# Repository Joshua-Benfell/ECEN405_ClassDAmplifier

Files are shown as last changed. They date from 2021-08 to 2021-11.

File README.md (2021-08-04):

# ECEN405_ClassDAmplifier

# Parts Checklist:
- [ ] [LPF 1](#lpf-1)
- [ ] [LPF 2](#lpf-2)
- [ ] [Gate Drivers](#gate-drivers) x 2
- [ ] Triangle wave generator block 
    - [ x ] [Comparator 1](#comparator-1) 
    - [ ] [Integrator](#integrator)
- [ ] [MOSFETs](#mosfets) x 2
- [ ] [Comparator 2](#comparator) 2
- [ ] [Inverter](#inverter)
- [ ] [Buffer](#buffer)

# System Overview
## Input Voltage
2V Peak to peak (+1V to -1V) with at least 1V input sensitivity. 

## Filters
### **Output Filter**
Needs to filter frequencies above 200Hz, but not the 200Hz point such that it has equivalent gain.  
Will likely need to be a Bridge Tied load (BTL) configuration, as BTL output filters do not require DC blocking caps, which limit the low frequency response of the amplifier, and can be quite large.  
  
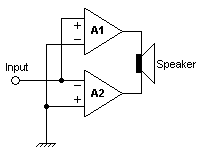
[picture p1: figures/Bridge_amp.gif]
  

Further reading: [on output filter types for class-d amplifiers](https://www.eetimes.com/understanding-output-filters-for-class-d-amplifiers/) and [BTL configurations on Wikipedia](https://en.wikipedia.org/wiki/Bridged_and_paralleled_amplifiers#Bridge-parallel_amplifier)  

### **Input Filter**
Cut-off point at 2kHz so that the cut-off is 1 decade above the 200Hz at the top of the bandwidth. This will avoid the phase change since it starts 1 decade before the cut-off. Make a Bode plot. No HPF for input as it is not needed. 
## Triangle Wave Generator
Possible approaches:
### **555 timer and an integrator**
To produce a clean triangle wave is complicated with a 555, simpler circuits with a 555 don't seem to guarantee a good output triangle wave. Furthermore, 55 timer circuits are more expensive and have a larger footprint.

### **Comparator integrator** 
A comparator integrator, is able to provide a reliably clean triangle wave and is fairly simple to implement.  
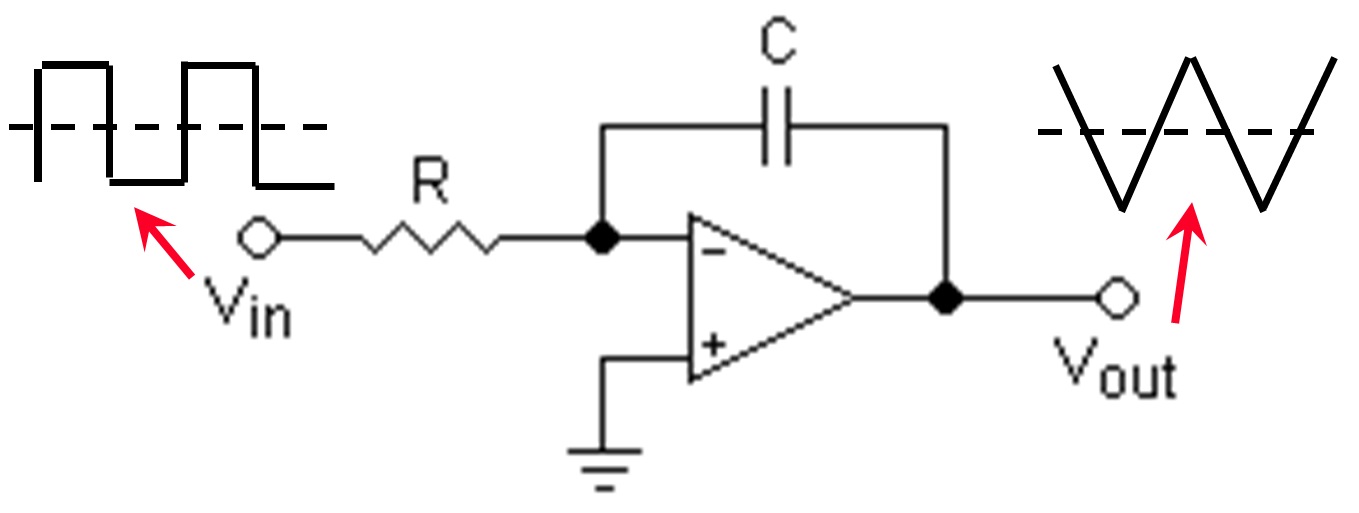
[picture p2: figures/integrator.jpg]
  
The frequency of the triangle wave will be above the audible range of frequencies at 22kHz.  
The package used will be: [MAX4016](https://www.digikey.co.nz/product-detail/en/maxim-integrated/MAX4016ESA/MAX4016ESA-ND/1702288)  
- 10V rail so that we don’t step down more again
- 5V middle because 50/50 v-divider is easy
- No dual rail because that is what a full bridge is for
- Also no whack shit - Danny B

## Switching Frequency
Two key constraints with switching frequency:  
1. As we are sampling an audio signal, it must be at least 10x the max frequency in our signal. The max signal frequency for the amplifier will be 200Hz, therefore the minimum sampling frequency must be 2kHz.
2. The switching frequency can't be audible, which means it must be outside of the audible range of frequencies to humans which is 20Hz - 20kHz. Adult humans typically can't hear more than 15 - 17kHz, making 20kHz a reasonable limit.
As a result the switching frequency must be **at least 20kHz**.

# Part Description and Justification
## LPF 1
## LPF 2
## Gate Drivers
### Requirements
- 18V Input
- 80W at 4 Ohms
- No integrated Fets
- Selectable Dead Time

### Selected
## Comparator 1
[MAX4016](https://www.digikey.co.nz/product-detail/en/maxim-integrated/MAX4016ESA/MAX4016ESA-ND/1702288)  
- 10V rail so that we don’t step down more again
- 5V middle because 50/50 v-divider is easy
- No dual rail because that is what a full bridge is for
- Also no whack shit - Danny B
## Integrator
## MOSFETs
## Comparator 2
## Inverter
## Buffer

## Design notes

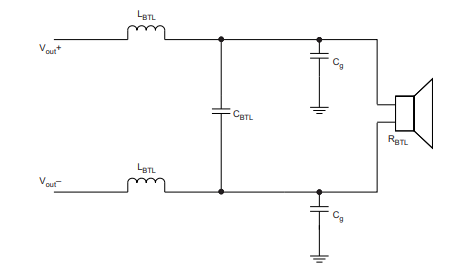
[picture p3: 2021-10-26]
figures/placeHolderOutputFilterSchematic.png

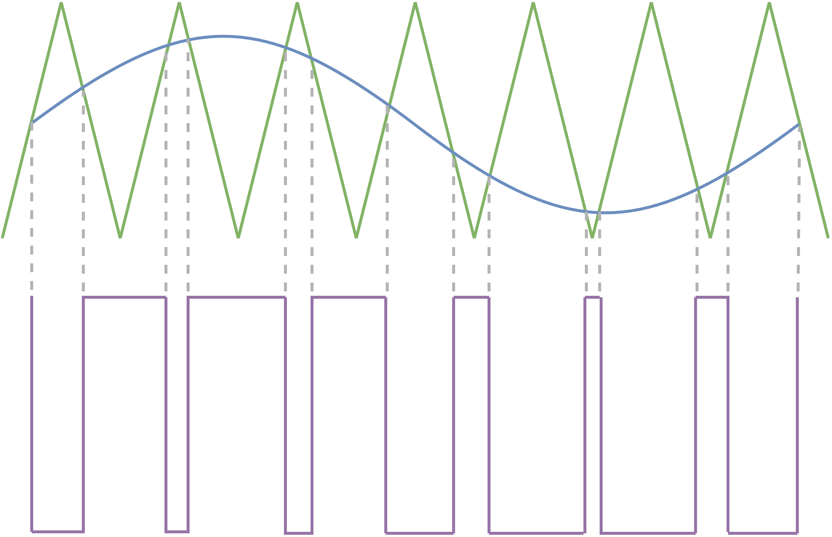
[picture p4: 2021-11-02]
figures/Waves_3.png

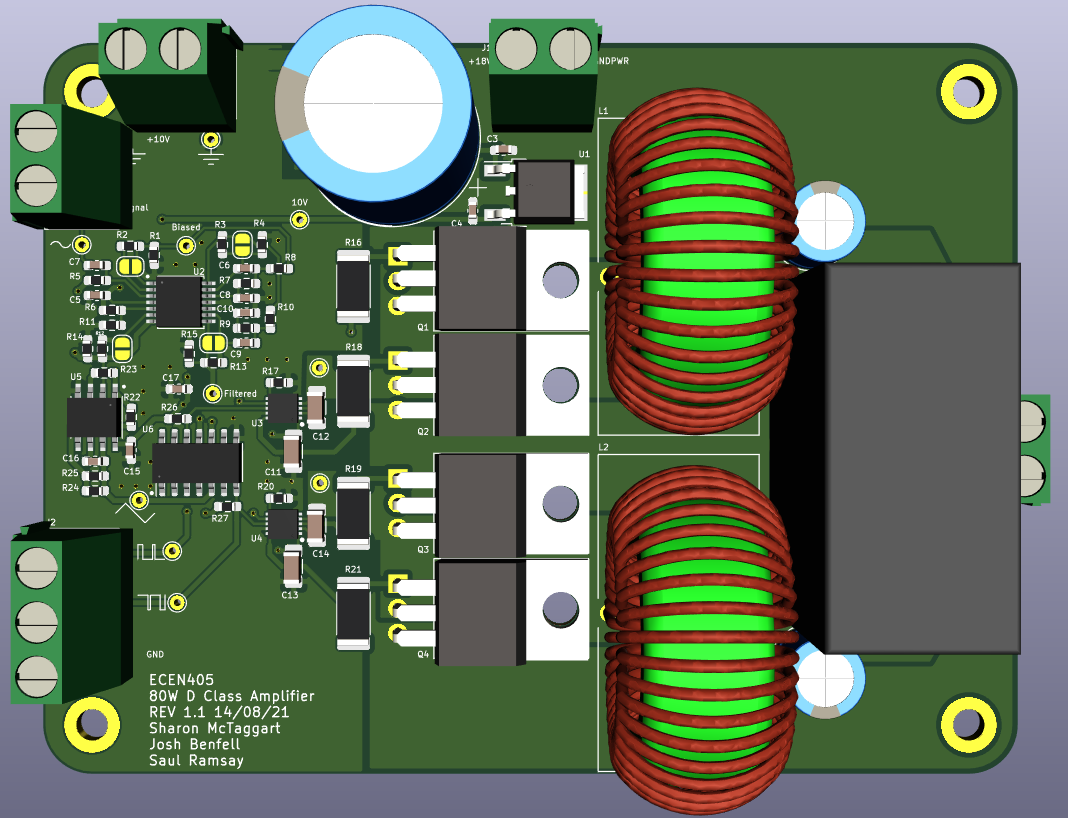
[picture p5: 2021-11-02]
figures/pcbRender.png

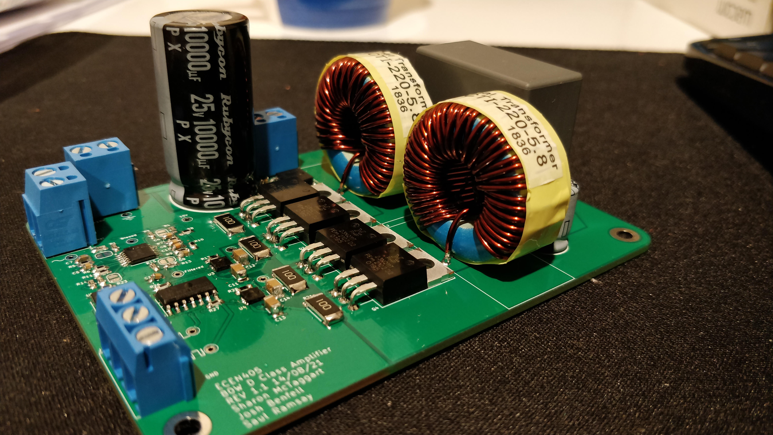
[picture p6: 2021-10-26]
figures/angleShot.jpg

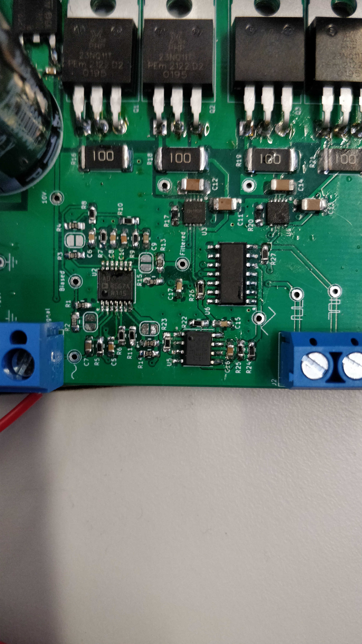
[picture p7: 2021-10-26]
figures/inputCloseup.jpg

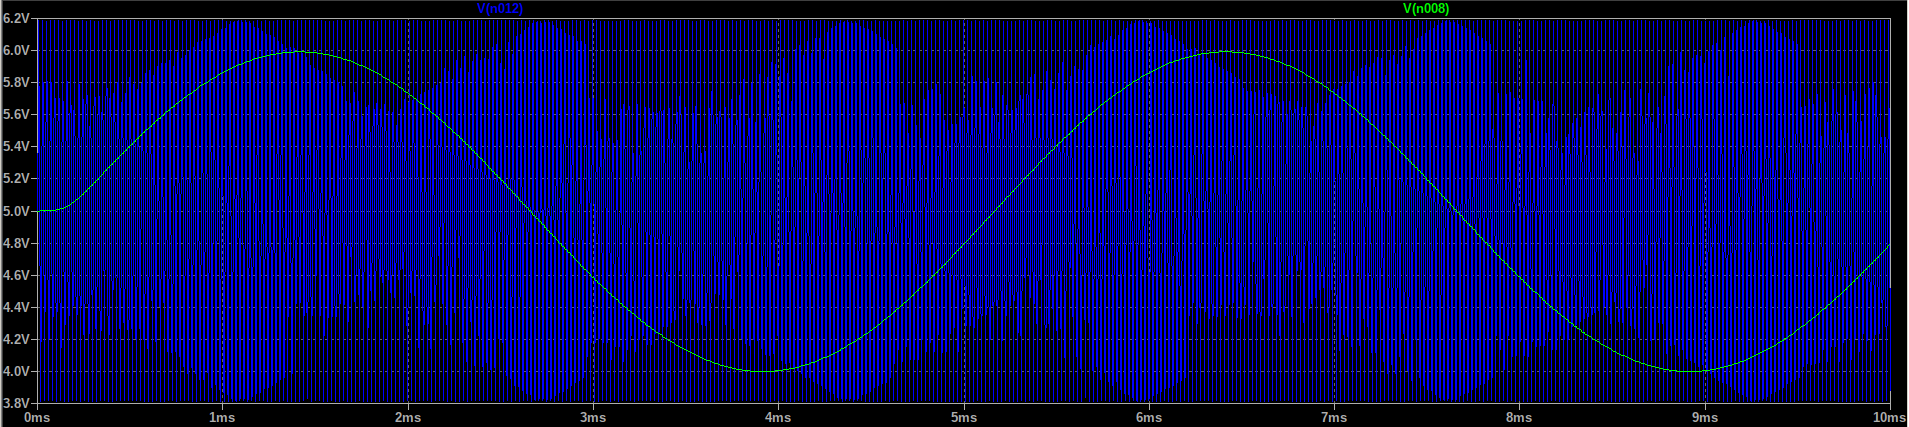
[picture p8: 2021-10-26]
figures/signalPlusTriangleWave.png

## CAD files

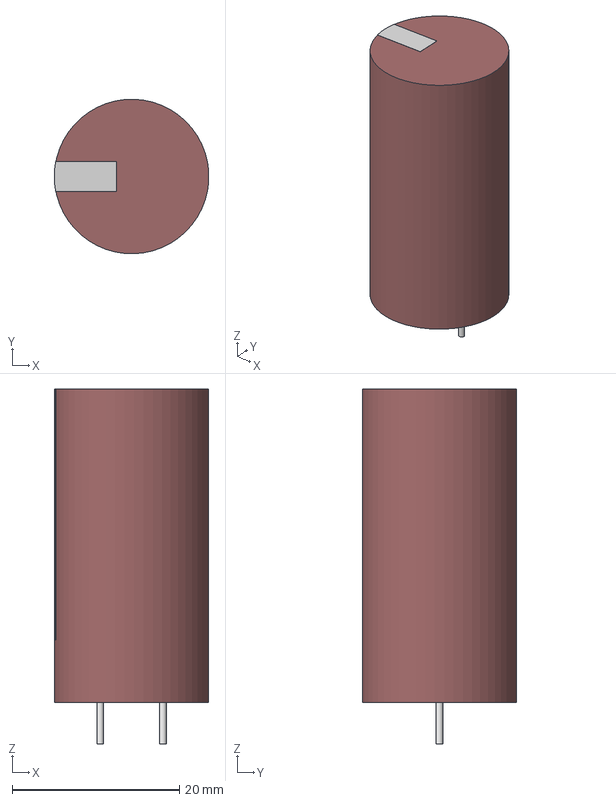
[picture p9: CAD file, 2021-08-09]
Kicad/3DModels/25PX10000MEFC18X35-5/CAP_PKPZ_18X35P5_RUB.step
18.5 x 18.5 x 42.5 mm

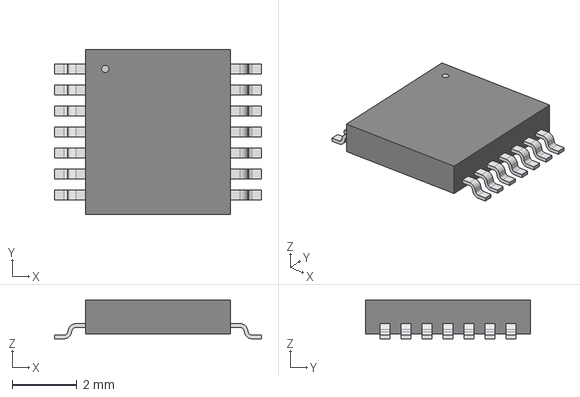
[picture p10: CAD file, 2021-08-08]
Kicad/3DModels/AD8567ARUZ/STEP/RU_14_ADI.step
6.40 x 5.11 x 1.20 mm

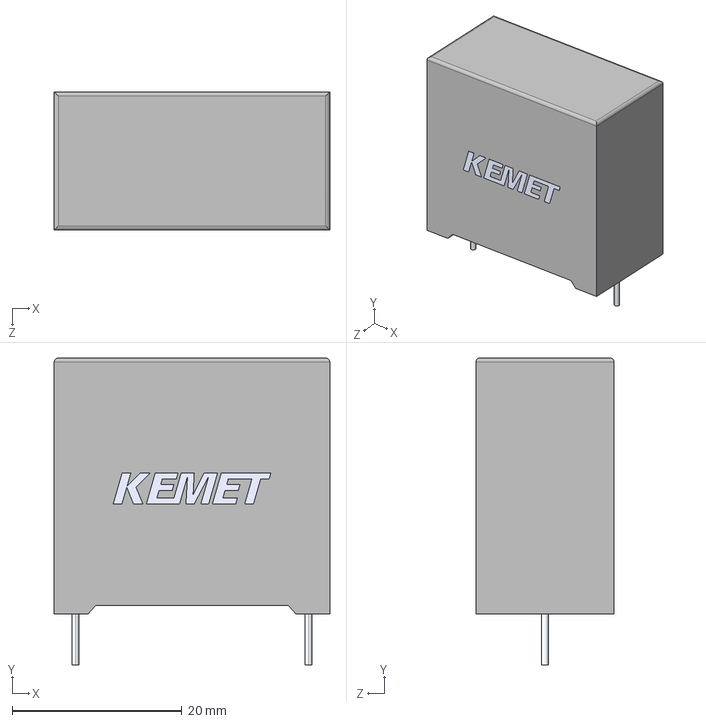
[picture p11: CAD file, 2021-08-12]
Kicad/3DModels/C4AQLBU5140M18K/C4AQLBU5140M18K.step
32.5 x 36.2 x 16.3 mm

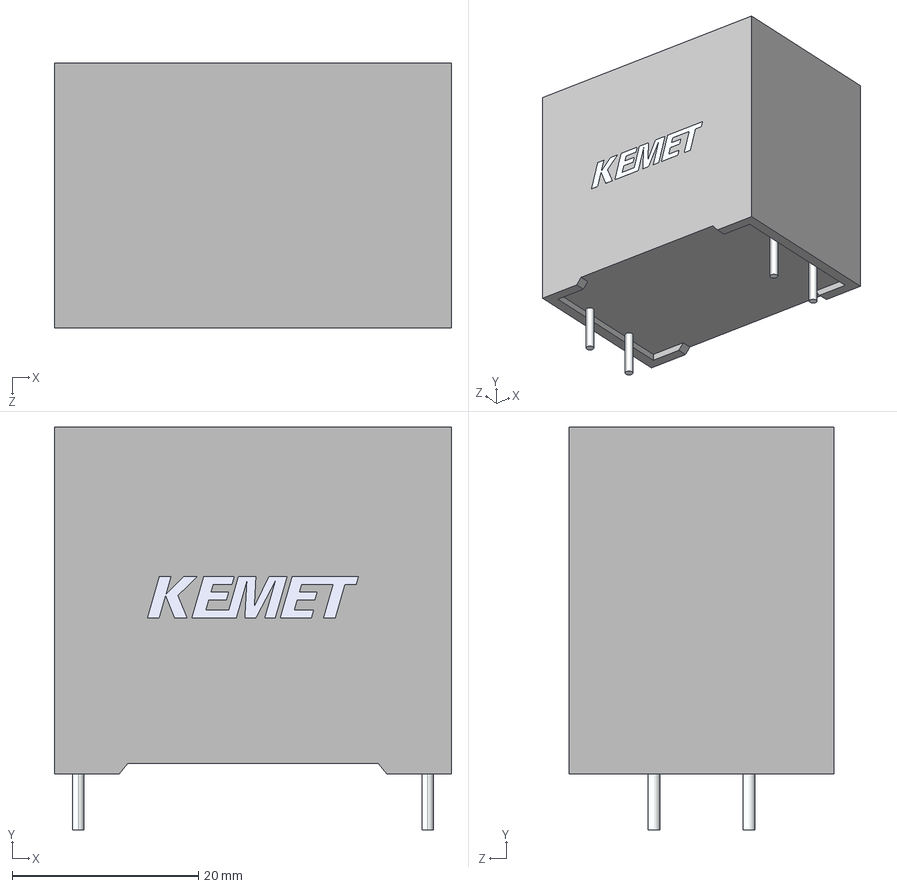
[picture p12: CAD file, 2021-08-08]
Kicad/3DModels/C4AQQBW5140A3JJ/C4AQQBW5140A3JJ.step
42.6 x 43.2 x 28.4 mm

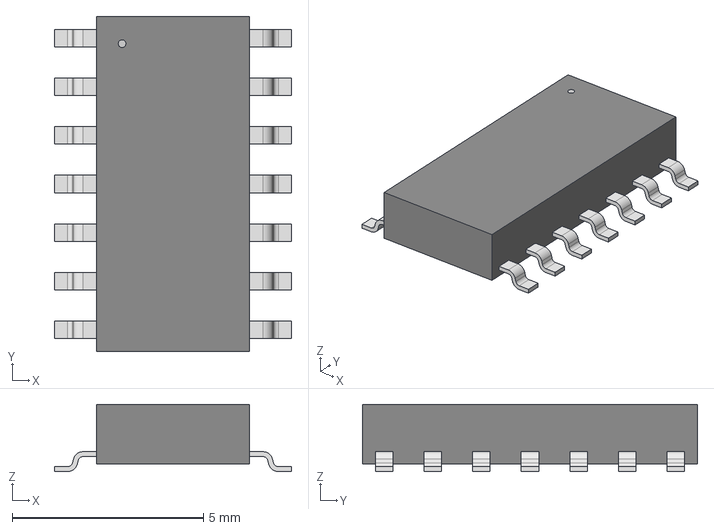
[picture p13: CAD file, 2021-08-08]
Kicad/3DModels/LM319DT/SO-14_STM.step
6.20 x 8.76 x 1.75 mm

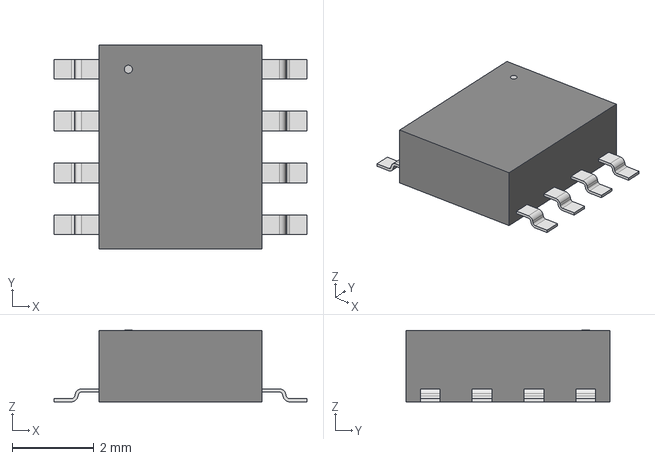
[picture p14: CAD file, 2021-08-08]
Kicad/3DModels/MAX4016ESA/STEP/21-0041B_8_MXM.step
6.20 x 5.00 x 1.75 mm

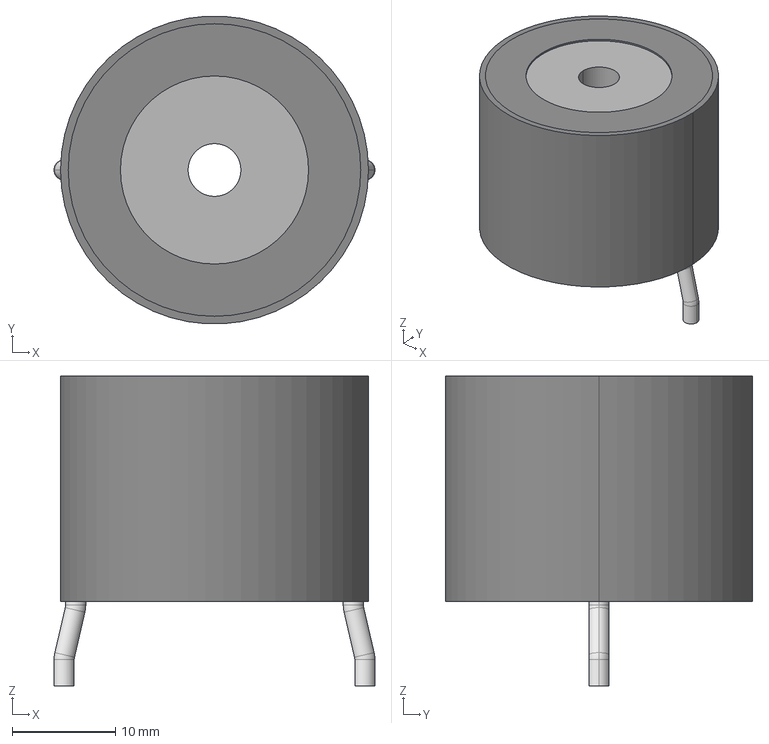
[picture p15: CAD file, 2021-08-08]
Kicad/3DModels/1422455C/1422455C_MUR.step
31.1 x 29.7 x 30.0 mm

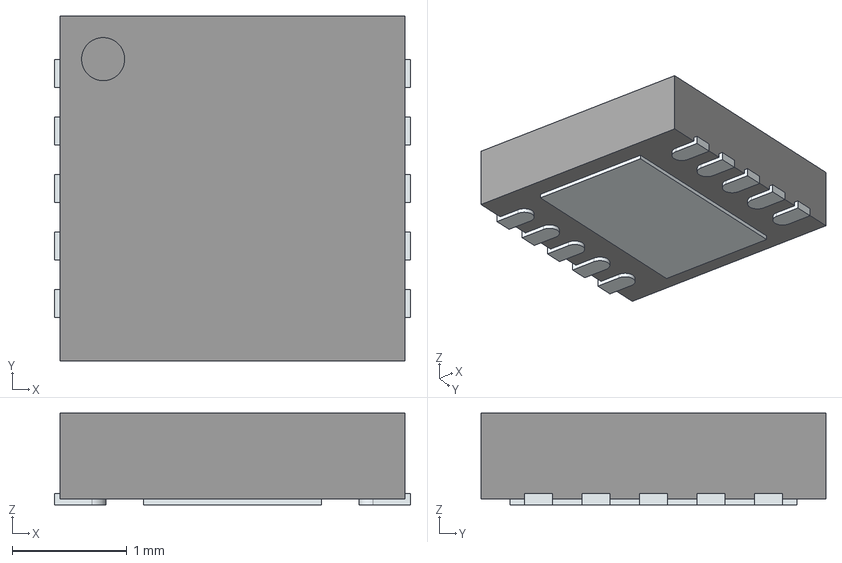
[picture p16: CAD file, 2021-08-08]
Kicad/3DModels/DGD05463FN-7/DGD05463FN-7.stp
3.10 x 3.00 x 0.8 mm
ThermalPin
PinsArrayLR

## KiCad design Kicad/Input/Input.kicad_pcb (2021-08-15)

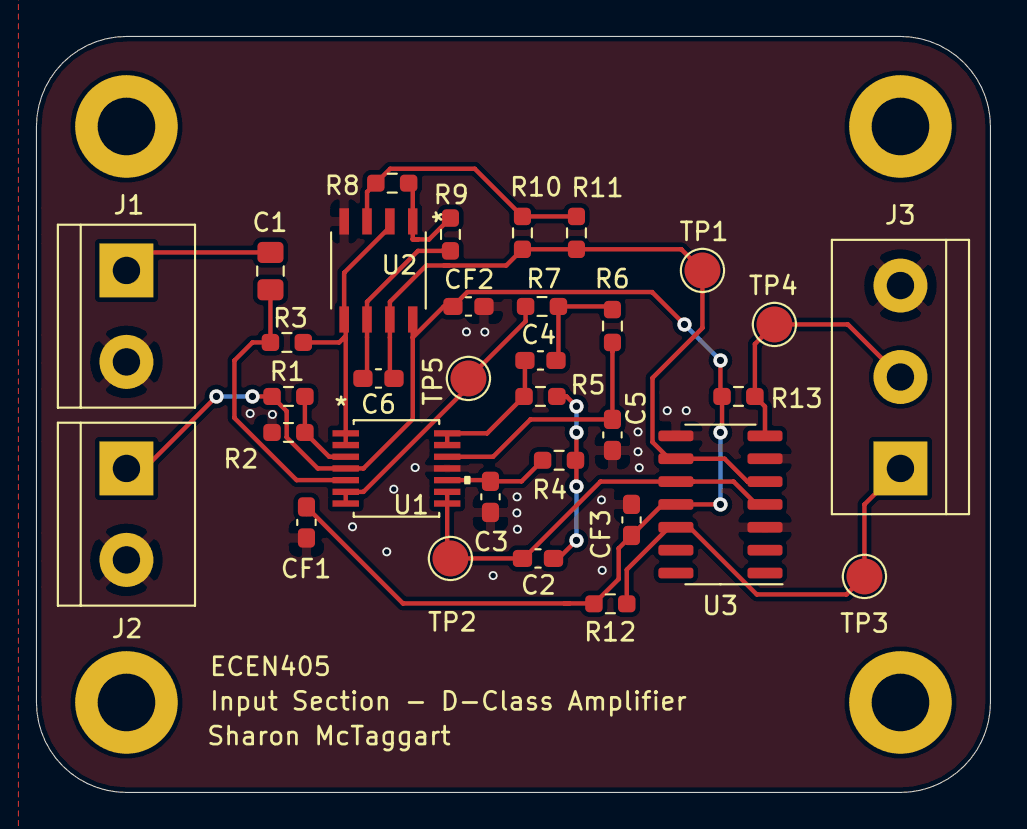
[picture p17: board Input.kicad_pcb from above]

Board: 2 copper layers, 53.0 x 42.0 mm, 37 parts (0 on the bottom side), 19 nets.

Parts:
C1: 10u; C_0805_2012Metric_Pad1.18x1.45mm_HandSolder
C2: 56n; C_0603_1608Metric_Pad1.08x0.95mm_HandSolder
C3: 5.6n; C_0603_1608Metric_Pad1.08x0.95mm_HandSolder
C4: 47n; C_0603_1608Metric_Pad1.08x0.95mm_HandSolder
C5: 4.7n; C_0603_1608Metric_Pad1.08x0.95mm_HandSolder
C6: 10n; C_0603_1608Metric_Pad1.08x0.95mm_HandSolder
CF1, CF2, CF3: 100n; C_0603_1608Metric_Pad1.08x0.95mm_HandSolder
H1, H2, H3, H4: MountingHole; MountingHole_3.2mm_M3_ISO7380_Pad
J1, J2: Conn_01x02; TerminalBlock_bornier-2_P5.08mm
J3: Conn_01x03; TerminalBlock_bornier-3_P5.08mm
R1, R2, R4, R12, R13: 10k; R_0603_1608Metric_Pad0.98x0.95mm_HandSolder
R3: 16k; R_0603_1608Metric_Pad0.98x0.95mm_HandSolder
R5: 750; R_0603_1608Metric_Pad0.98x0.95mm_HandSolder
R6: 22k; R_0603_1608Metric_Pad0.98x0.95mm_HandSolder
R7: 620; R_0603_1608Metric_Pad0.98x0.95mm_HandSolder
R8: 27k; R_0603_1608Metric_Pad0.98x0.95mm_HandSolder
R9: 2.2k; R_0603_1608Metric_Pad0.98x0.95mm_HandSolder
R10, R11: 12k; R_0603_1608Metric_Pad0.98x0.95mm_HandSolder
TP1, TP2, TP3, TP4, TP5: TestPoint; TestPoint_Pad_D2.0mm
U1: AD8567ARUZ
U2: MAX4016ESA+; MAX4016ESA&plus_
U3: LM319; SO-14_3.9x8.65mm_P1.27mm

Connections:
/Comparator/INV_PWM_OUT: J3.2, R13.2, TP4.1, U3.7
/Comparator/PWM_OUT: J3.1, R12.2, TP3.1, U3.12
/Comparator/SIG_IN: C2.2, TP2.1, U1.8, U1.9, U3.4, U3.10
/Comparator/TRIANGLE_IN: C6.1, R10.2, R11.2, TP1.1, U2.7, U3.5, U3.9
/LPF/BIASED_SIG: R7.1, TP5.1, U1.6, U1.7
/LPF/Filter_FirstStage: C4.1, R5.1, U1.13, U1.14
/LPF/SIG_IN: C1.2, J1.1
/LPF/VREF: R3.1, U1.1, U1.2, U2.2, U2.5
GND: C3.2, C5.2, CF1.2, CF2.2, CF3.2, J1.2, J2.2, J3.3, R2.2, U1.11, U2.4, U3.3, U3.6, U3.8
unnamed: C1.1, R3.2, U1.5
unnamed: C2.1, R4.1, R5.2
unnamed: C3.1, R4.2, U1.10
unnamed: C4.2, R6.1, R7.2
unnamed: C5.1, R6.2, U1.12
unnamed: C6.2, R9.1, U2.6
unnamed: R1.2, R2.1, U1.3
unnamed: R8.1, R9.2, U2.1
unnamed: R8.2, R10.1, R11.1, U2.3
VCC: CF1.1, CF2.1, CF3.1, J2.1, R1.1, R12.1, R13.1, U1.4, U2.8, U3.11

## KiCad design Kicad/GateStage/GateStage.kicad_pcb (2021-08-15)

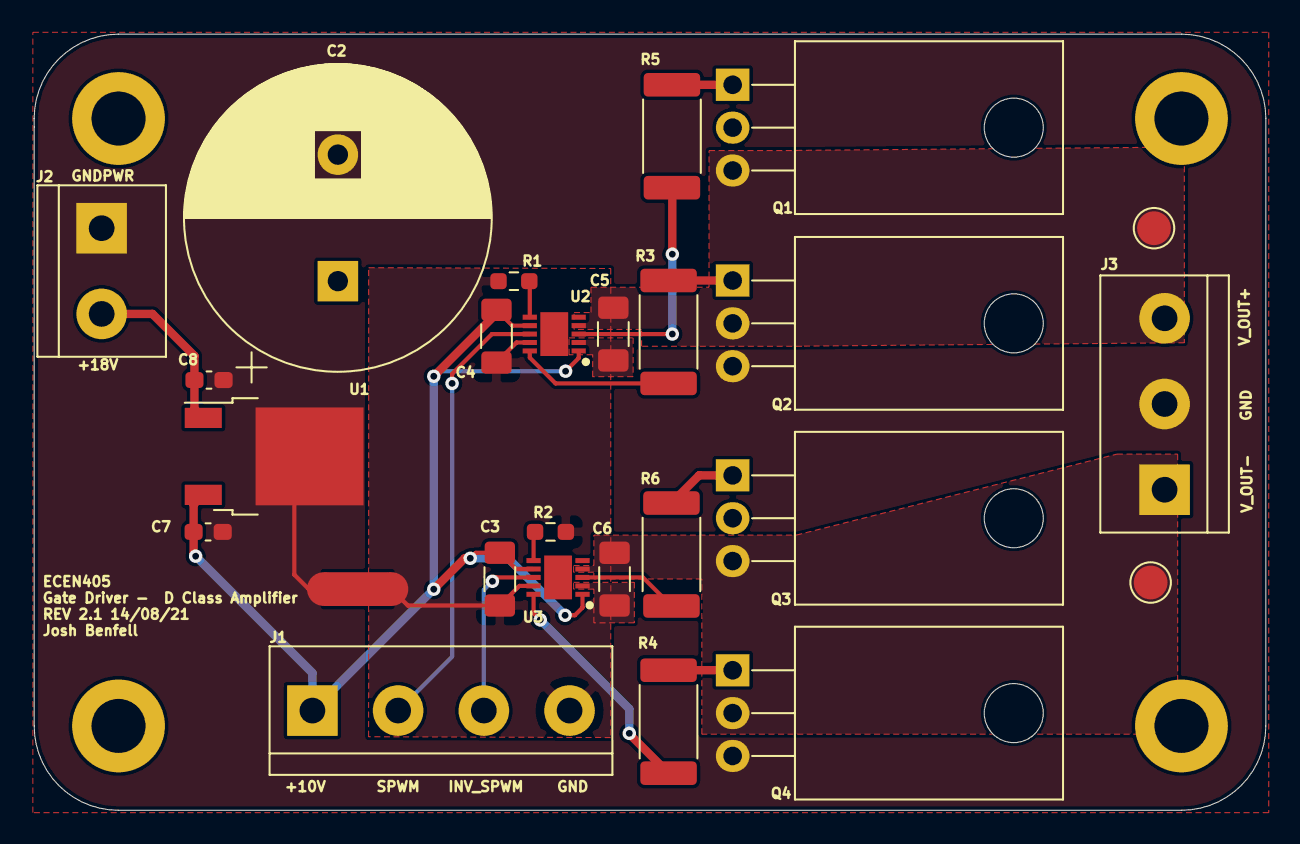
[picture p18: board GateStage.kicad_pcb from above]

Board: 2 copper layers, 73.0 x 46.0 mm, 31 parts (1 on the bottom side), 20 nets.

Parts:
C1, C3, C4, C5, C6: 10u 50V; C_1206_3216Metric_Pad1.33x1.80mm_HandSolder
C2: 10m; CP_Radial_D18.0mm_P7.50mm
C7: 100n; C_0603_1608Metric_Pad1.08x0.95mm_HandSolder
C8: 330n; C_0603_1608Metric_Pad1.08x0.95mm_HandSolder
H1, H2, H3, H4: MountingHole; MountingHole_3.2mm_M3_ISO14580_Pad
J1: Conn_01x04; TerminalBlock_bornier-4_P5.08mm
J2: Conn_01x02; TerminalBlock_bornier-2_P5.08mm
J3: Conn_01x03; TerminalBlock_bornier-3_P5.08mm
NT1: Net-Tie_2; NetTie-2_SMD_Pad2.0mm
Q1, Q2, Q3, Q4: PHP23NQ11T,127; TO-220-3_Horizontal_TabDown
R1, R2: 20k; R_0603_1608Metric_Pad0.98x0.95mm_HandSolder
R3, R4, R5, R6: 10; R_2512_6332Metric_Pad1.40x3.35mm_HandSolder
TP1, TP2: TestPoint; TestPoint_Pad_D2.0mm
U1: L78M10ABDT; TO-252-2
U2, U3: DGD05463FN-7; SON50P300X300X80-11N-D

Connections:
/H-Bridge/V_DT1: R1.1, U2.6
/H-Bridge/V_DT2: R2.1, U3.6
/H-Bridge/V_OUT+: C5.1, J3.3, Q1.3, Q2.2, TP1.1, U2.4
/H-Bridge/V_OUT-: C6.1, J3.1, Q3.3, Q4.2, TP2.1, U3.4
/INV_PWM: J1.3, U3.8
/PWM: J1.2, U2.8
GND: C3.1, C4.1, J1.4, NT1.1, R1.2, R2.2, U2.9, U3.9
GNDPWR: C1.2, C2.2, C7.2, C8.2, J2.1, J3.2, NT1.2, Q2.3, Q4.3, U1.2
unnamed: C5.2, U2.2
unnamed: C6.2, U3.2
unnamed: Q1.1, R5.1
unnamed: Q2.1, R3.1
unnamed: Q3.1, R6.1
unnamed: Q4.1, R4.1
unnamed: R3.2, U2.10
unnamed: R4.2, U3.10
unnamed: R5.2, U2.3
unnamed: R6.2, U3.3
VCC: C3.2, C4.2, C7.1, J1.1, U1.3, U2.1, U2.7, U3.1, U3.7
VDD: C1.1, C2.1, C8.1, J2.2, Q1.2, Q3.2, U1.1

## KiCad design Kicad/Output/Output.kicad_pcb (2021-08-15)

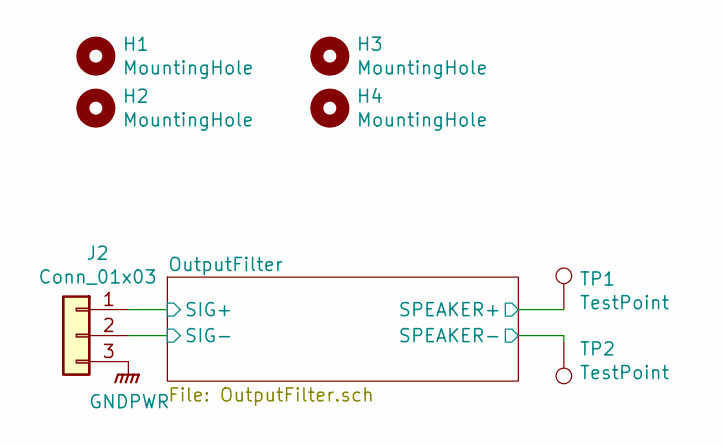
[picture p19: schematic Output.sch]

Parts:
H1, H2, H3, H4: MountingHole; MountingHole_3.2mm_M3_ISO7380_Pad
J2: Conn_01x03; TerminalBlock_bornier-3_P5.08mm
TP1, TP2: TestPoint; TestPoint_Pad_D2.0mm

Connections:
/OutputFilter/SIG+: J2.1; also elsewhere on the board
/OutputFilter/SIG-: J2.2; also elsewhere on the board
/OutputFilter/SPEAKER+: TP1.1; also elsewhere on the board
/OutputFilter/SPEAKER-: TP2.1; also elsewhere on the board
GNDPWR: J2.3; also elsewhere on the board

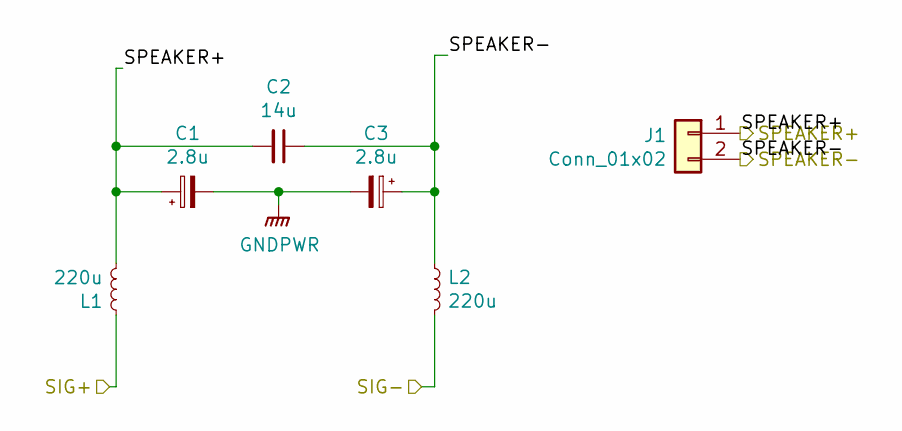
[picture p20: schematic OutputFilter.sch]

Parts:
C1, C3: 2.8u; CP_Radial_D8.0mm_P3.50mm
C2: 14u; C4AQLBU5140M18K
J1: Conn_01x02; TerminalBlock_bornier-2_P5.08mm
L1, L2: 220u; IND_HCTI-220-5.8

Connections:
/OutputFilter/SIG+: L1.1; also elsewhere on the board
/OutputFilter/SIG-: L2.2; also elsewhere on the board
/OutputFilter/SPEAKER+: C1.1, C2.2, J1.1, L1.2; also elsewhere on the board
/OutputFilter/SPEAKER-: C2.1, C3.1, J1.2, L2.1; also elsewhere on the board
GNDPWR: C1.2, C3.2; also elsewhere on the board

Board: 2 copper layers, 13 parts (0 on the bottom side), 5 nets, no tracks yet.

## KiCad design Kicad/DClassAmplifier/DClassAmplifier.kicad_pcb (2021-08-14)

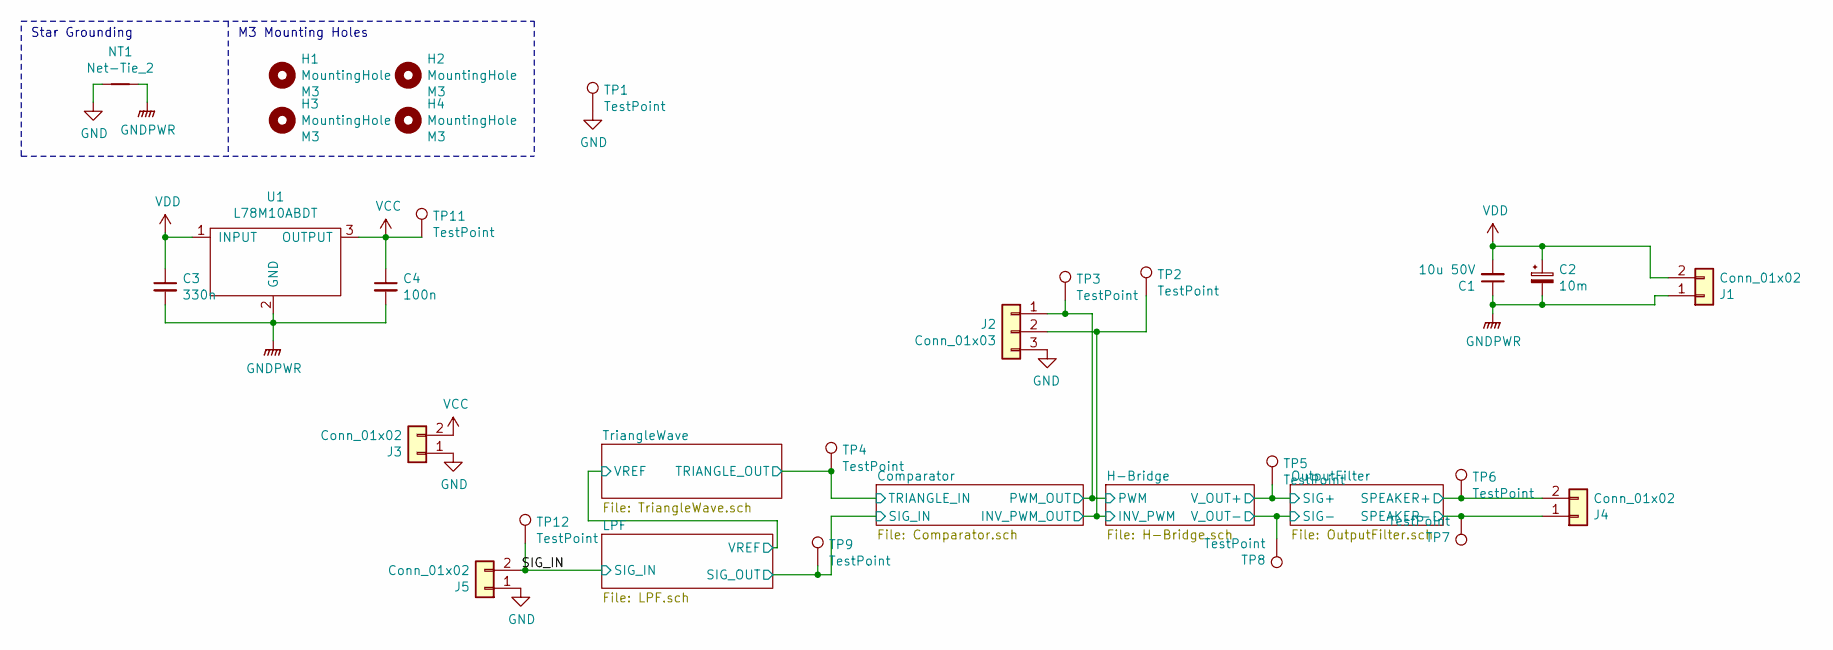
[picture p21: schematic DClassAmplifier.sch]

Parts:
C1: 10u 50V; C_1206_3216Metric_Pad1.33x1.80mm_HandSolder
C2: 10m; CP_Radial_D18.0mm_P7.50mm
C3: 330n; C_0603_1608Metric_Pad1.08x0.95mm_HandSolder
C4: 100n; C_0603_1608Metric_Pad1.08x0.95mm_HandSolder
H1, H2, H3, H4: MountingHole; MountingHole_3.2mm_M3_ISO7380_Pad
J1, J3, J4, J5: Conn_01x02; TerminalBlock_bornier-2_P5.08mm
J2: Conn_01x03; TerminalBlock_bornier-3_P5.08mm
NT1: Net-Tie_2; NetTie-2_SMD_Pad2.0mm
TP1, TP2, TP3, TP4, TP5, TP6, TP7, TP8, TP9, TP11, TP12: TestPoint; TestPoint_THTPad_D1.5mm_Drill0.7mm
U1: L78M10ABDT; TO-252-2

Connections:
/Comparator/SIG_IN: TP9.1; also elsewhere on the board
/Comparator/TRIANGLE_IN: TP4.1; also elsewhere on the board
/H-Bridge/INV_PWM: J2.2, TP2.1; also elsewhere on the board
/H-Bridge/PWM: J2.1, TP3.1; also elsewhere on the board
/OutputFilter/SIG+: TP5.1; also elsewhere on the board
/OutputFilter/SIG-: TP8.1; also elsewhere on the board
/OutputFilter/SPEAKER+: J4.2, TP6.1; also elsewhere on the board
/OutputFilter/SPEAKER-: J4.1, TP7.1; also elsewhere on the board
/SIG_IN: J5.2, TP12.1; also elsewhere on the board
GND: J2.3, J3.1, J5.1, NT1.1, TP1.1; also elsewhere on the board
GNDPWR: C1.1, C2.2, C3.2, C4.2, J1.1, NT1.2, U1.2 (GND); also elsewhere on the board
VCC: C4.1, J3.2, TP11.1, U1.3 (OUTPUT); also elsewhere on the board
VDD: C1.2, C2.1, C3.1, J1.2, U1.1 (INPUT); also elsewhere on the board

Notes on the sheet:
Star Grounding
M3 Mounting Holes

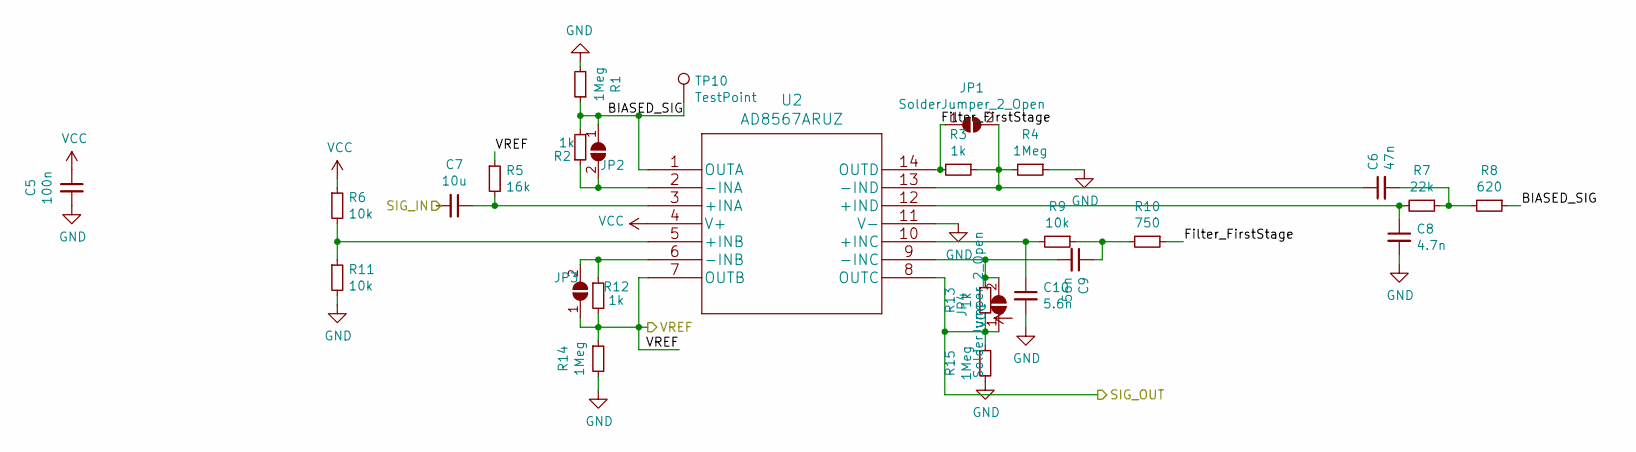
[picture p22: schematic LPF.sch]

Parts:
C5: 100n; C_0603_1608Metric_Pad1.08x0.95mm_HandSolder
C6: 47n; C_0603_1608Metric_Pad1.08x0.95mm_HandSolder
C7: 10u; C_0603_1608Metric_Pad1.08x0.95mm_HandSolder
C8: 4.7n; C_0603_1608Metric_Pad1.08x0.95mm_HandSolder
C9: 56n; C_0603_1608Metric_Pad1.08x0.95mm_HandSolder
C10: 5.6n; C_0603_1608Metric_Pad1.08x0.95mm_HandSolder
JP1, JP2, JP3, JP4: SolderJumper_2_Open; SolderJumper-2_P1.3mm_Open_RoundedPad1.0x1.5mm
R1, R4, R14, R15: 1Meg; R_0603_1608Metric_Pad0.98x0.95mm_HandSolder
R2, R3, R12, R13: 1k; R_0603_1608Metric_Pad0.98x0.95mm_HandSolder
R5: 16k; R_0603_1608Metric_Pad0.98x0.95mm_HandSolder
R6, R9, R11: 10k; R_0603_1608Metric_Pad0.98x0.95mm_HandSolder
R7: 22k; R_0603_1608Metric_Pad0.98x0.95mm_HandSolder
R8: 620; R_0603_1608Metric_Pad0.98x0.95mm_HandSolder
R10: 750; R_0603_1608Metric_Pad0.98x0.95mm_HandSolder
TP10: TestPoint; TestPoint_THTPad_D1.5mm_Drill0.7mm
U2: AD8567ARUZ

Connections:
/Comparator/SIG_IN: JP4.1 (A), R13.2, R15.1, U2.8 (OUTC); also elsewhere on the board
/LPF/BIASED_SIG: JP2.1 (A), R1.1, R2.2, R8.1, TP10.1, U2.1 (OUTA)
/LPF/Filter_FirstStage: JP1.1 (A), R3.2, R10.1, U2.14 (OUTD)
/LPF/VREF: JP3.1 (A), R5.1, R12.2, R14.1, U2.7 (OUTB); also elsewhere on the board
/SIG_IN: C7.2; also elsewhere on the board
GND: C5.2, C8.2, C10.2, R1.2, R4.1, R11.2, R14.2, R15.2, U2.11 (V-); also elsewhere on the board
unnamed: C6.1, JP1.2 (B), R3.1, R4.2, U2.13 (-IND)
unnamed: C6.2, R7.1, R8.2
unnamed: C7.1, R5.2, U2.3 (+INA)
unnamed: C8.1, R7.2, U2.12 (+IND)
unnamed: C9.1, R9.1, R10.2
unnamed: C9.2, JP4.2 (B), R13.1, U2.9 (-INC)
unnamed: C10.1, R9.2, U2.10 (+INC)
unnamed: JP2.2 (B), R2.1, U2.2 (-INA)
unnamed: JP3.2 (B), R12.1, U2.6 (-INB)
unnamed: R6.2, R11.1, U2.5 (+INB)
VCC: C5.1, R6.1, U2.4 (V+); also elsewhere on the board

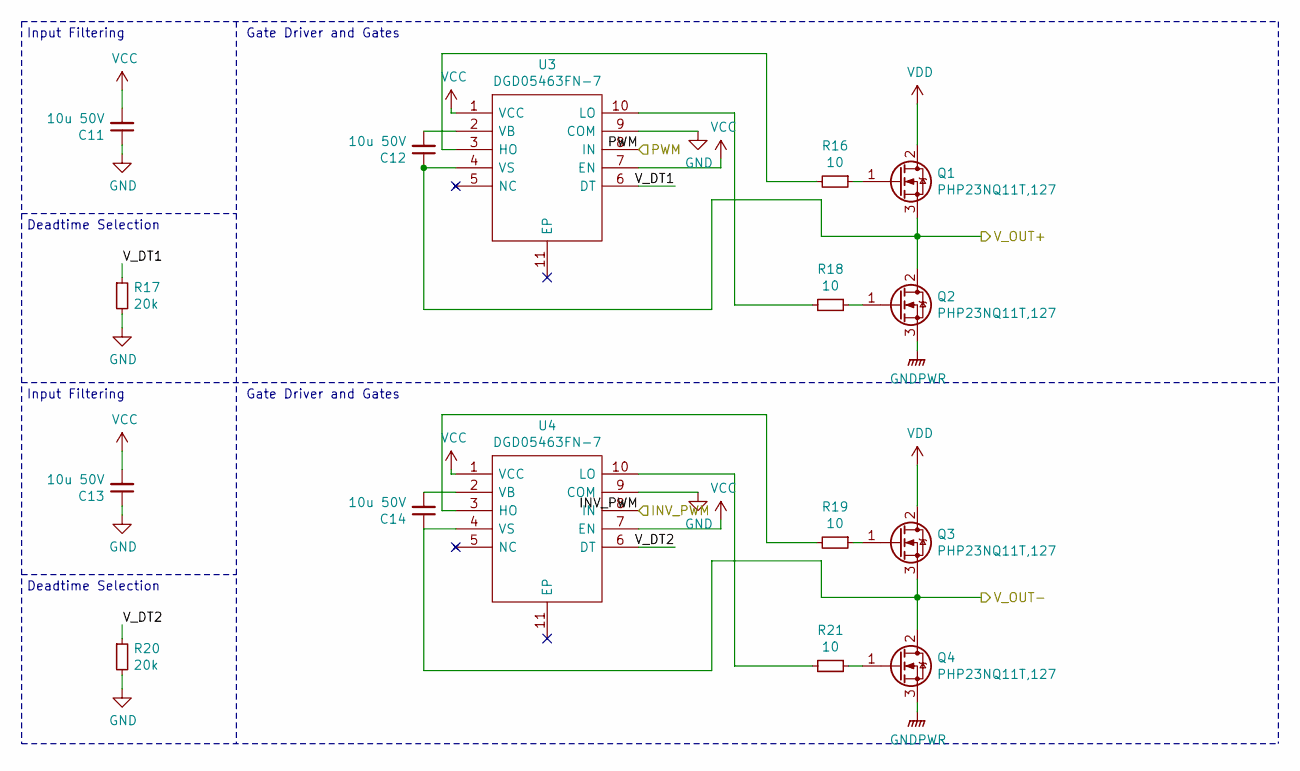
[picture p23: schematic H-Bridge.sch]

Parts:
C11, C12, C13, C14: 10u 50V; C_1206_3216Metric_Pad1.33x1.80mm_HandSolder
Q1, Q2, Q3, Q4: PHP23NQ11T,127; TO-220-3_Horizontal_TabDown
R16, R18, R19, R21: 10; R_2512_6332Metric_Pad1.40x3.35mm_HandSolder
R17, R20: 20k; R_0603_1608Metric_Pad0.98x0.95mm_HandSolder
U3, U4: DGD05463FN-7; SON50P300X300X80-11N-D; Manufacturer_Part_Number DGD05463FN-7; Mouser Part Number 621-DGD05463FN-7

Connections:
/H-Bridge/INV_PWM: U4.8 (IN); also elsewhere on the board
/H-Bridge/PWM: U3.8 (IN); also elsewhere on the board
/H-Bridge/V_DT1: R17.1, U3.6 (DT)
/H-Bridge/V_DT2: R20.1, U4.6 (DT)
/OutputFilter/SIG+: C12.1, Q1.3 (S), Q2.2 (D), U3.4 (VS); also elsewhere on the board
/OutputFilter/SIG-: C14.1, Q3.3 (S), Q4.2 (D), U4.4 (VS); also elsewhere on the board
GND: C11.1, C13.1, R17.2, R20.2, U3.9 (COM), U4.9 (COM); also elsewhere on the board
GNDPWR: Q2.3 (S), Q4.3 (S); also elsewhere on the board
unnamed: C12.2, U3.2 (VB)
unnamed: C14.2, U4.2 (VB)
unnamed: Q1.1 (G), R16.1
unnamed: Q2.1 (G), R18.1
unnamed: Q3.1 (G), R19.1
unnamed: Q4.1 (G), R21.1
unnamed: R16.2, U3.3 (HO)
unnamed: R18.2, U3.10 (LO)
unnamed: R19.2, U4.3 (HO)
unnamed: R21.2, U4.10 (LO)
VCC: C11.2, C13.2, U3.1 (VCC), U3.7 (EN), U4.1 (VCC), U4.7 (EN); also elsewhere on the board
VDD: Q1.2 (D), Q3.2 (D); also elsewhere on the board

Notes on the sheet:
Input Filtering
Deadtime Selection
Gate Driver and Gates

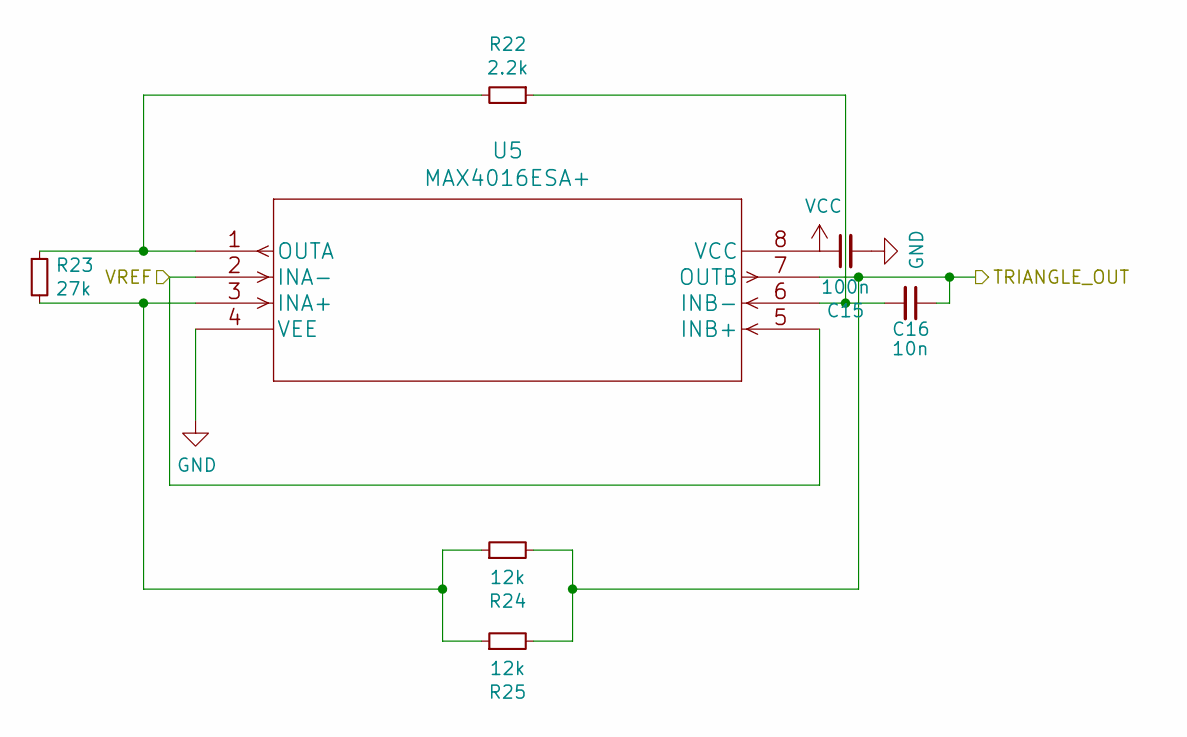
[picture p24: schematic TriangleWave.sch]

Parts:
C15: 100n; C_0603_1608Metric_Pad1.08x0.95mm_HandSolder
C16: 10n; C_0603_1608Metric_Pad1.08x0.95mm_HandSolder
R22: 2.2k; R_0603_1608Metric_Pad0.98x0.95mm_HandSolder
R23: 27k; R_0603_1608Metric_Pad0.98x0.95mm_HandSolder
R24, R25: 12k; R_0603_1608Metric_Pad0.98x0.95mm_HandSolder
U5: MAX4016ESA+; MAX4016ESA&plus_

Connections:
/Comparator/TRIANGLE_IN: C16.1, R24.2, R25.2, U5.7 (OUTB); also elsewhere on the board
/LPF/VREF: U5.2 (INA-), U5.5 (INB+); also elsewhere on the board
GND: C15.2, U5.4 (VEE); also elsewhere on the board
unnamed: C16.2, R22.1, U5.6 (INB-)
unnamed: R22.2, R23.1, U5.1 (OUTA)
unnamed: R23.2, R24.1, R25.1, U5.3 (INA+)
VCC: C15.1, U5.8 (VCC); also elsewhere on the board

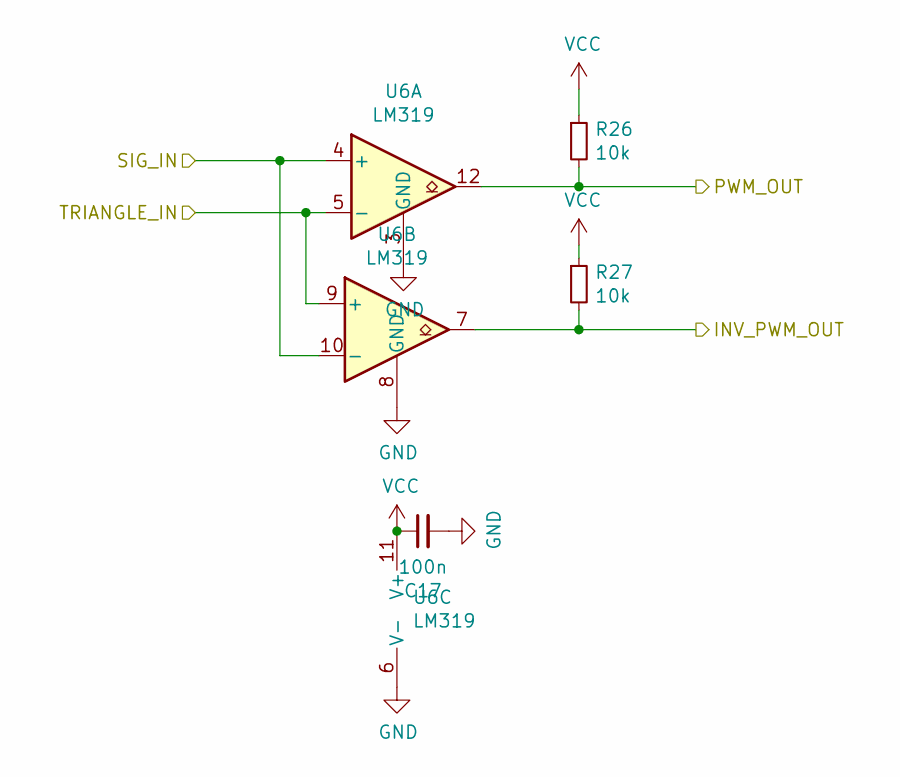
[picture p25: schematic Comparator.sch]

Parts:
C17: 100n; C_0603_1608Metric_Pad1.08x0.95mm_HandSolder
R26, R27: 10k; R_0603_1608Metric_Pad0.98x0.95mm_HandSolder
U6: LM319; SO-14_3.9x8.65mm_P1.27mm

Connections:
/Comparator/SIG_IN: U6.4 (+), U6.10 (-); also elsewhere on the board
/Comparator/TRIANGLE_IN: U6.5 (-), U6.9 (+); also elsewhere on the board
/H-Bridge/INV_PWM: R27.2, U6.7; also elsewhere on the board
/H-Bridge/PWM: R26.2, U6.12; also elsewhere on the board
GND: C17.2, U6.3 (GND), U6.6 (V-), U6.8 (GND); also elsewhere on the board
VCC: C17.1, R26.1, R27.1, U6.11 (V+); also elsewhere on the board

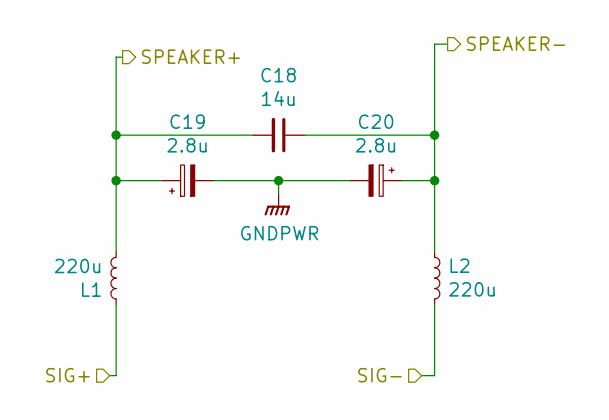
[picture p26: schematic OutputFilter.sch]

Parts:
C18: 14u; C4AQLBU5140M18K
C19, C20: 2.8u; CP_Radial_D8.0mm_P3.50mm
L1, L2: 220u; IND_HCTI-220-5.8

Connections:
/OutputFilter/SIG+: L1.1; also elsewhere on the board
/OutputFilter/SIG-: L2.2; also elsewhere on the board
/OutputFilter/SPEAKER+: C18.2, C19.1, L1.2; also elsewhere on the board
/OutputFilter/SPEAKER-: C18.1, C20.1, L2.1; also elsewhere on the board
GNDPWR: C19.2, C20.2; also elsewhere on the board

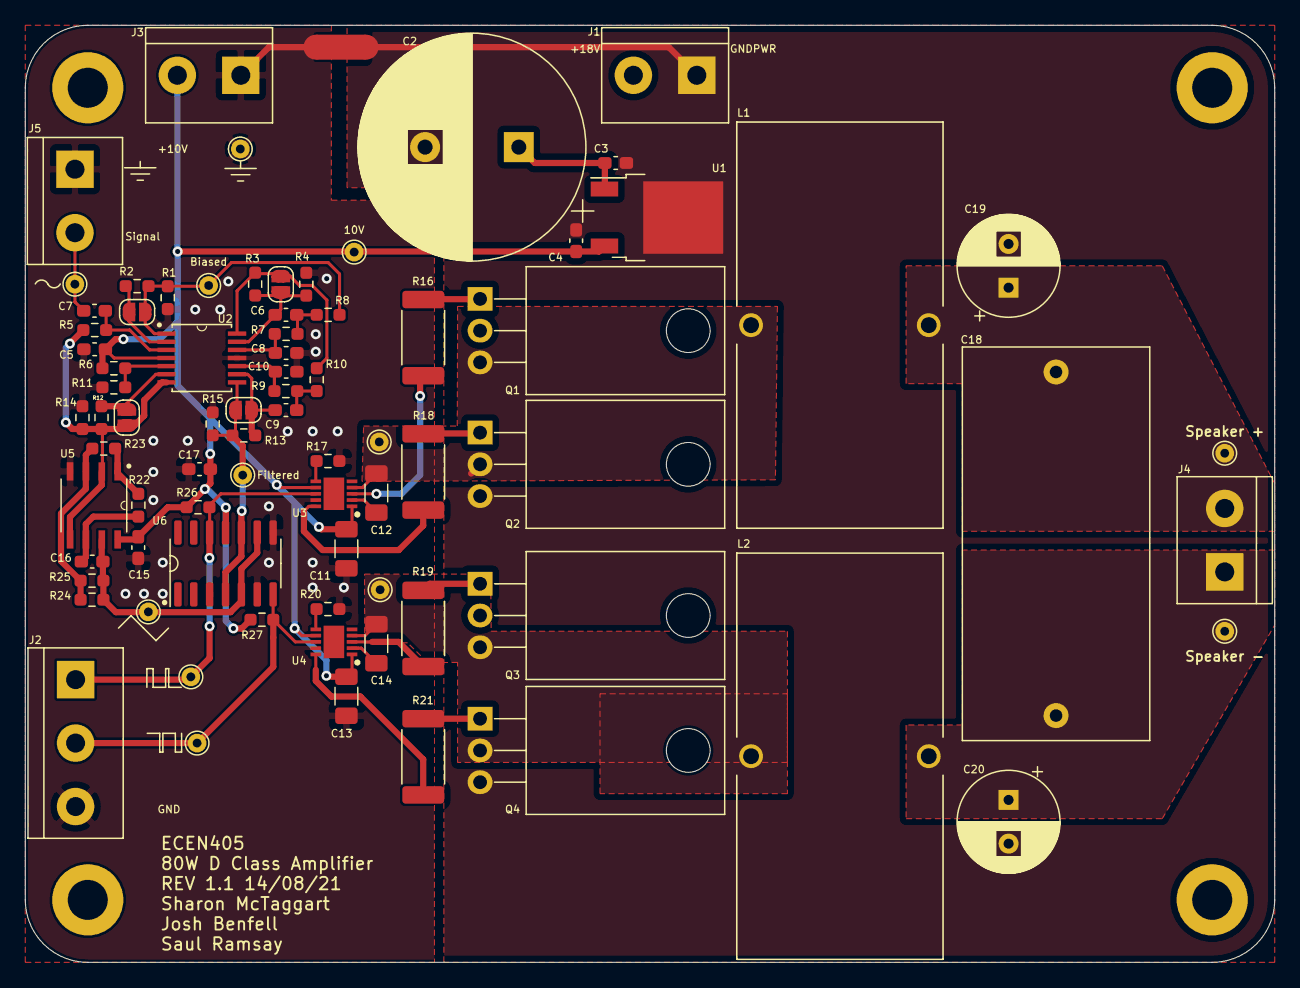
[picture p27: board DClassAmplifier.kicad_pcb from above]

Board: 2 copper layers, 100.0 x 75.0 mm, 85 parts (1 on the bottom side), 41 nets.

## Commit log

2021-07-21 Initial Kicad File Commit
    [DClassAmplifier.kicad_pcb, DClassAmplifier.sch, OutputFilter.sch]
2021-07-25 Added Net-Tied Grounds and Filter schematic
    [DClassAmplifier.sch, OutputFilter.sch]
2021-07-25 Create Additional Needed Hierarchical Schematics. Add Mounting Holes
    [DClassAmplifier.sch, Feedback.sch, H-Bridge.sch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]
2021-07-25 Add Gate Driver Library and To Schematic
    [DClassAmplifier.sch, Feedback.sch, H-Bridge.sch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]
2021-07-27 FET Selection
    [DClassAmplifier.sch, H-Bridge.sch]
2021-07-29 Sizing Gate Driver Components
    [DClassAmplifier.sch, H-Bridge.sch]
2021-07-30 Start Output Filter Spice File
2021-07-30 Work on getting filters working
2021-07-30 Added Dummy Comparator to schematic and duplicated drive.
    [DClassAmplifier.sch, Feedback.sch, H-Bridge.sch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]
2021-08-03 Hierarchical Comparator Sheet
    Updated Gate Driver as well
    [Comparator.sch, DClassAmplifier.sch, Feedback.sch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]
2021-08-03 Input stage
2021-08-03 Add files via upload
    Summing circuit with dual 10V rails to add a 5V bias
2021-08-03 10V input triangle wave
2021-08-03 Combine Triangle wave and Input Biasing/Filtering
2021-08-03 Lol Whoops, changes??
    Oh it was me moving things around a little bit
    [DClassAmplifier.sch]
2021-08-04 Design Updates for LTSpice and KiCad
    [Comparator.sch, DClassAmplifier.sch, Feedback.sch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]
2021-08-07 Values fixed
    40kHz triangle wave. Active LPF with 2kHz cut-off frequency.
2021-08-07 Update Output Filter
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2021-08-08 Output & Input Filter Final Designs
2021-08-08 Finish off Main Part of Schematic
    [Comparator.sch, DClassAmplifier.sch, Feedback.sch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]
2021-08-08 updates to schematic
    [Comparator.sch, DClassAmplifier.sch, H-Bridge.sch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]
2021-08-08 Add Filter Op Amp
    [21-0041B_8_MXM.step, RU_14_ADI.step]
2021-08-08 Update Opamp for Input Filter
    [Comparator.sch, DClassAmplifier.sch, H-Bridge.sch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]
2021-08-08 Added footprints to schematic
    [Comparator.sch, DClassAmplifier.sch, H-Bridge.sch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]
2021-08-08 Update Terminal Block Footprints
    [Comparator.sch, H-Bridge.sch, LPF.sch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]
2021-08-08 Add Test Points
    [Comparator.sch, DClassAmplifier.sch, H-Bridge.sch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]
2021-08-08 Load Components into PCBDOC
    [DClassAmplifier.kicad_pcb, LPF.sch, TriangleWave.sch]
2021-08-08 Add 3D Models
    [1422455C_MUR.step, C4AQQBW5140A3JJ.step, DClassAmplifier.kicad_pcb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]
2021-08-09 Add 10m Resevoir Cap
    [CAP_PKPZ_18X35P5_RUB.step, DClassAmplifier.kicad_pcb, DClassAmplifier.sch]
2021-08-10 Added input to global schematic
    Changed the sig_in net label in the LPF sheet to a hierarchical net label of the same name
    [DClassAmplifier.sch, H-Bridge.sch, LPF.sch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]
2021-08-10 Create Separate Projects for Each Board Layout
    [Comparator.sch, GateStage.kicad_pcb, GateStage.sch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]
2021-08-11 Prepared O/P Filter PCB for track layout
    Laid out components for Output Filter PCB compactly ready for tracks to be drawn. Have drawn out precise margin lines too.
    [Output.kicad_pcb, Output.sch, OutputFilter.sch]
2021-08-11 Gate Drive Board V 1
    [GateStage.kicad_pcb, GateStage.sch, H-Bridge.sch]
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2021-08-11 Saving changes before updating library
    [Output.kicad_pcb]
2021-08-11 OP Filter PCB Done
    OP Filter PCB finished
    [Output.kicad_pcb, OutputFilter.sch]
2021-08-11 Input PCB added
    [Comparator.sch, Input.kicad_pcb, Input.sch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]
2021-08-12 SilkS on Gate Driver Board
    [GateStage.kicad_pcb]
2021-08-12 Flipped J2, added connector labels
    Flipped J2 and re-drew planes to connect Sig + and - respectively .
    Also added labels for all the connections for J1 and J2 as well as the testpoints
    [Output.kicad_pcb]
2021-08-12 PCB for input and added filter caps
    [Comparator.sch, Input.kicad_pcb, LPF.sch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]
2021-08-12 Switched around component sides to match connector
    [Output.kicad_pcb]
2021-08-12 Moved filter caps (slightly)
    Shifted them such that they're as close as possible to the larger cap with enough physical clearance, and made the both symmetrical too
    [Output.kicad_pcb]
2021-08-12 Add SilkScreen to Film Cap Footprint
    [Output.kicad_pcb]
2021-08-12 Add Alternative Cap Footprint
2021-08-12 Add Alternative Cap 3D Model
    [C4AQLBU5140M18K.step]
2021-08-12 Combined Board
    [Comparator.sch, DClassAmplifier.kicad_pcb, DClassAmplifier.sch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]
2021-08-14 Add 10V Reg and Reroute
    [Comparator.sch, DClassAmplifier.kicad_pcb, DClassAmplifier.sch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]
2021-08-14 Graphics and SilkScreen Improvement
    [DClassAmplifier.kicad_pcb, DClassAmplifier.sch]
2021-08-14 Generate Fabrication Outputs
    [DClassAmplifier-B_Cu.gbl, DClassAmplifier-B_Mask.gbs, DClassAmplifier-B_Paste.gbp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]
2021-08-14 Whoops final Save
    [DClassAmplifier.kicad_pcb]
2021-08-14 Redo GateStage Board
    [GateStage.kicad_pcb, GateStage.sch, H-Bridge.sch]
2021-08-14 Move Combined Board Fabrication Outputs
    [DClassAmplifier-B_Cu.gbl, DClassAmplifier-B_Mask.gbs, DClassAmplifier-B_Paste.gbp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]
2021-08-14 Create GateStage Fabrication Outputs
    [GateStage-B_Cu.gbl, GateStage-B_Mask.gbs, GateStage-B_Paste.gbp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]
2021-08-15 Make Output Filter Board Smaller
    [Output.kicad_pcb, OutputFilter.sch]
2021-08-15 Label GateStage Board, Redo Planes, Regen Fab Outs
    [GateStage-B_Cu.gbl, GateStage-B_Mask.gbs, GateStage-B_Paste.gbp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]
2021-08-15 resized input board
    [Input.kicad_pcb]
2021-08-15 added gerber and drill files
    [Input-B_Cu.gbl, Input-B_Mask.gbs, Input-B_Paste.gbp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]
2021-08-16 Final Fab Files
    [DClassAmplifier-B_Cu.gbl, DClassAmplifier-B_Mask.gbs, DClassAmplifier-B_Paste.gbp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]

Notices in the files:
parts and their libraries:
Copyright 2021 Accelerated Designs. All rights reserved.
